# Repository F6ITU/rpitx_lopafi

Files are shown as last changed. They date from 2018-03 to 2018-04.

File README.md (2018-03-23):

# rpitx_lopafi

Low pass filter for the Raspberry-Pi based TX RF transceiver

YAOHKP ! Yet another open hardware kicad project

LoPaFi is a "keep it simple stupid" version of a low pass filter with a Raspberry-Pi (or Up Board) form factor.

It is intended to fit on a RP Board running RpiTX by F5OEO

https://github.com/F5OEO/rpitx

This filter is made of 5 different Cauer filters with rejection notches on F2 and F3, using T50 toroids and 1206 smd caps

Switching is made with NEC EC2-5NU miniature relays (Kemet, NEC, Axicom), directly powered by the SoC board

Each relay is directly driven by a  bufferized and software driven GPIO

For more information, pse refer to the Wiki hosted on this very same wiki page
 
 This hardware development is "under construction" as long as a first version hasn't been "branched" 
 
 Please, do not fork before the first stable release unless you intend to contribute to the main development
 
 This project is protected by the CERN Open Hardware Licence https://www.ohwr.org/projects/cernohl/wiki

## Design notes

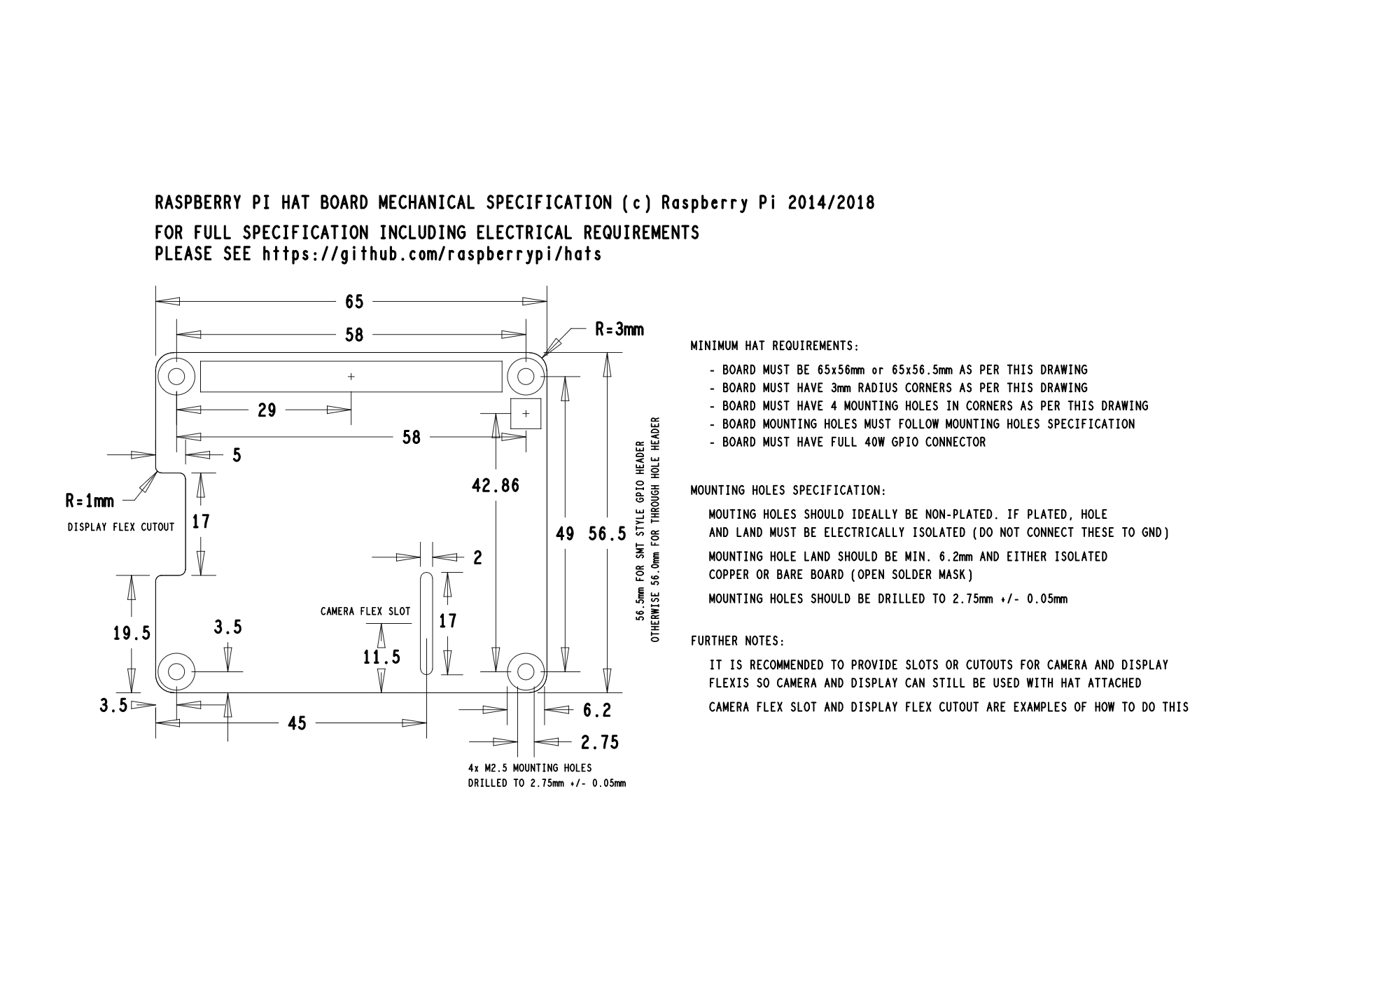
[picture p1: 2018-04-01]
datasheets/raspi specs.png

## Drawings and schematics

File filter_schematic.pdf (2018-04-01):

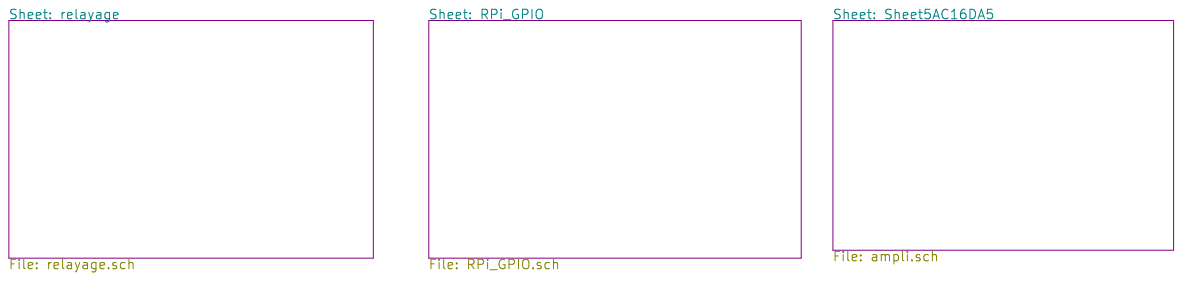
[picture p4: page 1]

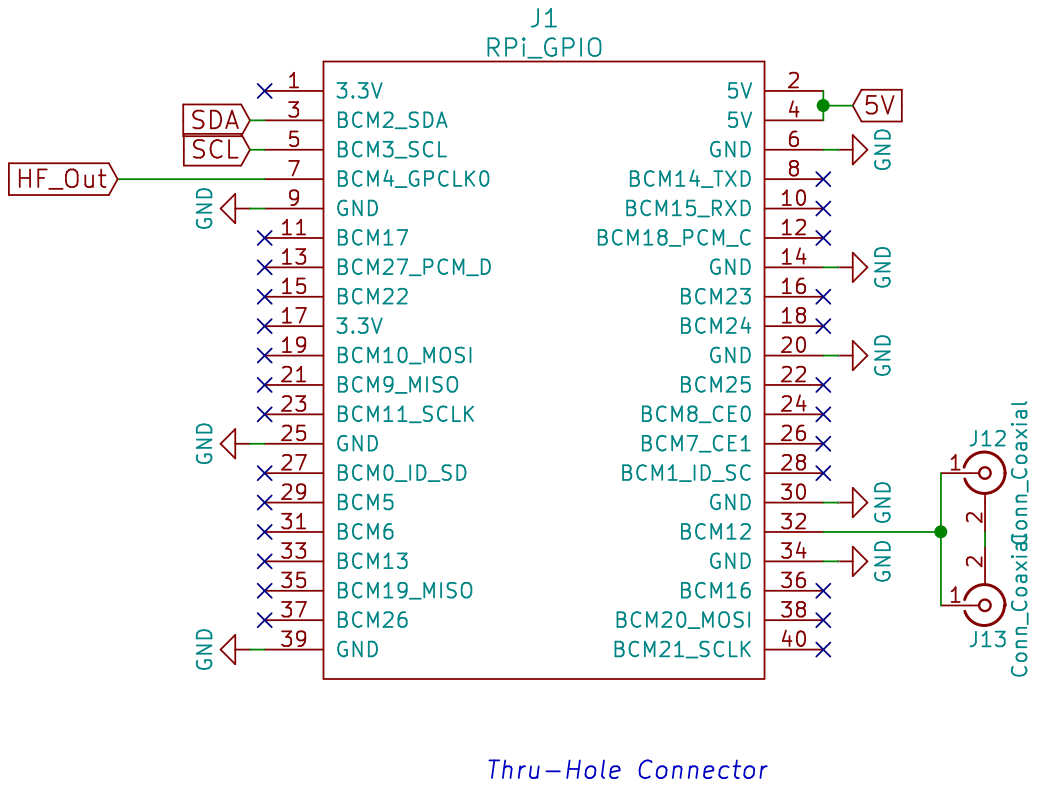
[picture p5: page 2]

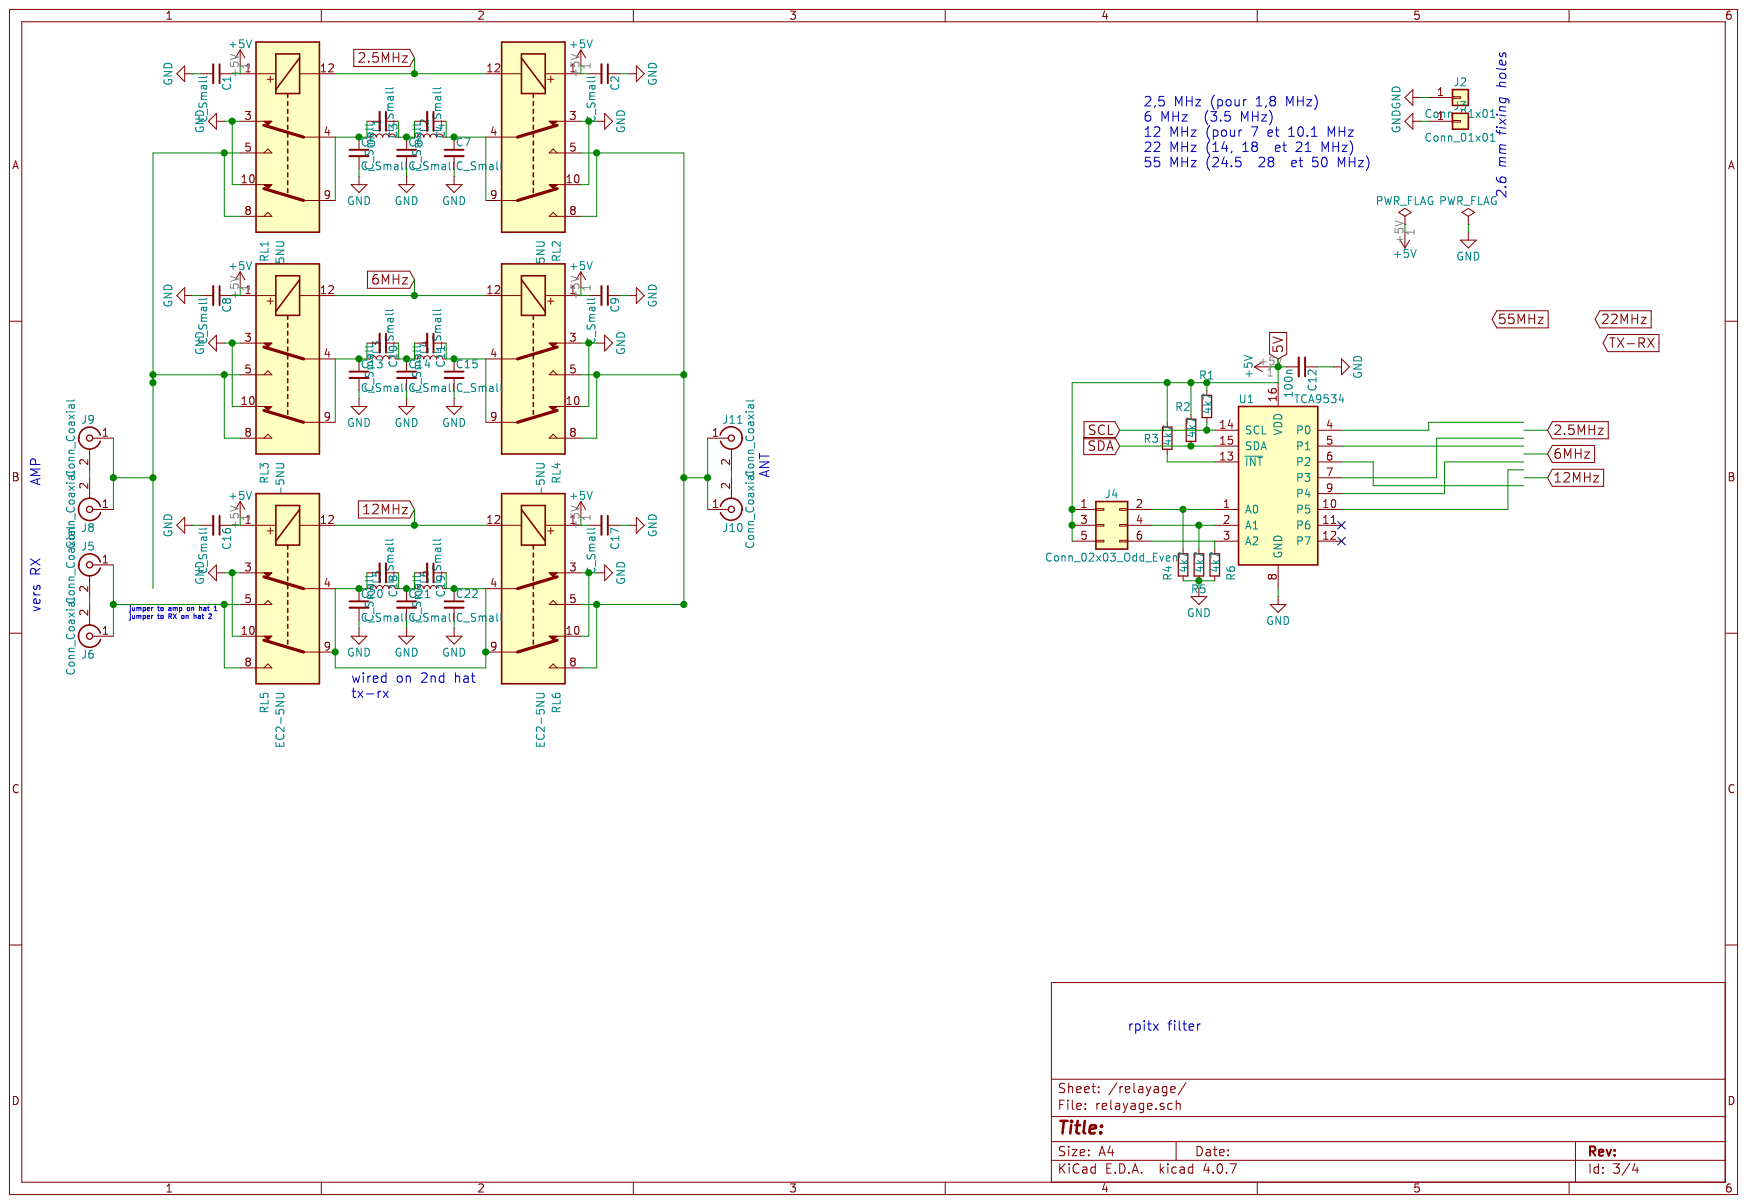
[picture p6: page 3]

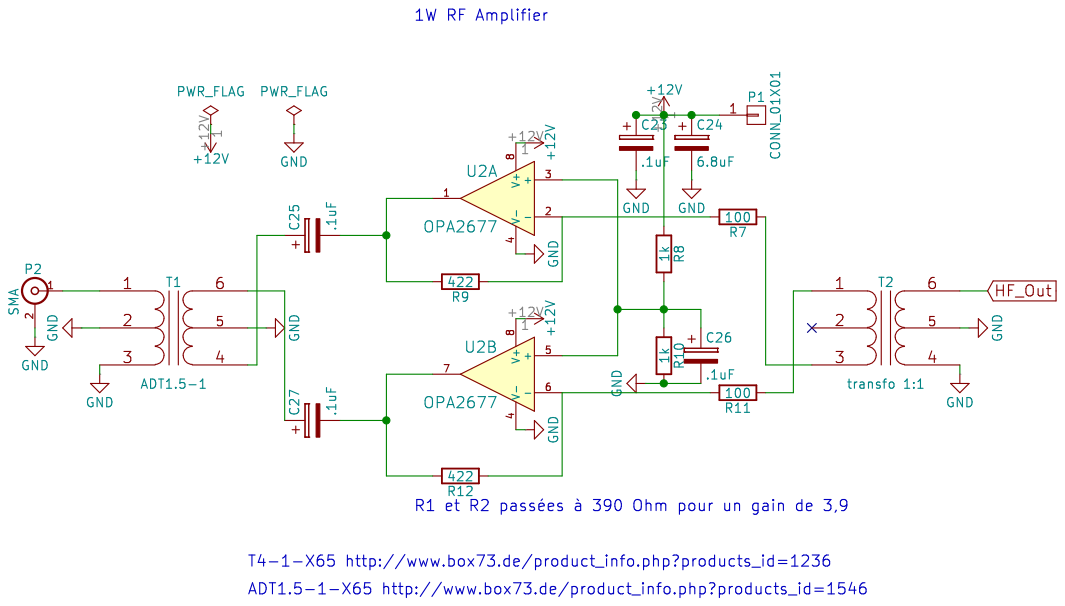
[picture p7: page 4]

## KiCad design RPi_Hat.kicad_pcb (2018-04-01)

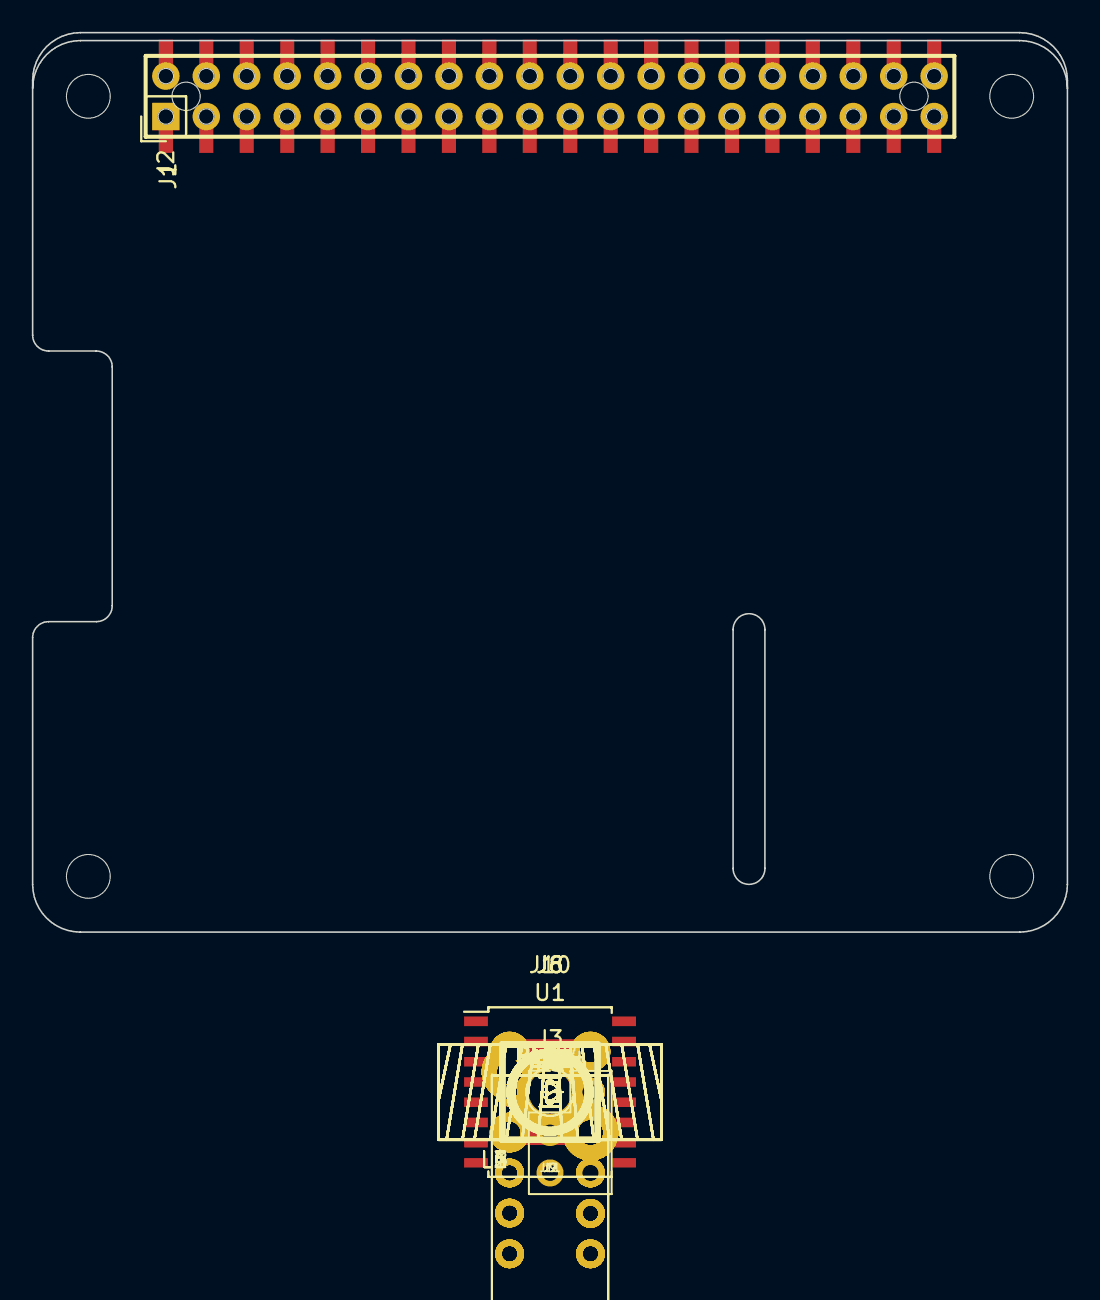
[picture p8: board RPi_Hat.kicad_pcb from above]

Board: 2 copper layers, 65.0 x 56.5 mm, 51 parts (0 on the bottom side), 26 nets, no tracks yet.

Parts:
C1, C2, C3, C4, C5, C6, C7, C8, C9, C10, C11, C13, C14, C15, C16, C17, C18, C19, C20, C21, C22: C_Small; C_1206_3216Metric_Pad1.24x1.80mm_HandSolder
C12: 100n; C_1206_3216Metric_Pad1.24x1.80mm_HandSolder
J1: RPi_GPIO; Samtec_HLE-120-02-XXX-DV-BE-XX-XX
J2: Conn_01x01; Pin_Header_Straight_2x20
J3: Conn_01x01; MountingHole_2.7mm_M2.5_DIN965_Pad
J4: Conn_02x03_Odd_Even; PinHeader_2x03_P2.54mm_Vertical
J6, J8, J10: Conn_Coaxial; SMA_EDGE_NRW
J7, J9, J11: Conn_Coaxial; SMA_PINS
L1, L2, L3, L4, L5, L6: L_Small; T50_V_THT
R1, R2, R3, R4, R5, R6: 4k7; R_0805_2012Metric_Pad1.15x1.50mm_HandSolder
RL1, RL2, RL3, RL4, RL5, RL6: EC2-5NU; Relay_DPDT_NEC_EC2
U1: TCA9534; SOIC-16W_7.5x10.3mm_P1.27mm

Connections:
2.5MHz: RL1.12, RL2.12, U1.4
5V: C1.1, C2.2, C8.1, C9.2, C12.2, C16.1, C17.2, J4.1, J4.3, J4.5, R1.1, R2.1, R3.1, RL1.1, RL2.1, RL3.1, RL4.1, RL5.1, RL6.1, U1.16
6MHz: RL3.12, RL4.12, U1.5
12MHz: RL5.12, RL6.12, U1.6
GND: C1.2, C2.1, C5.2, C6.2, C7.2, C8.2, C9.1, C12.1, C13.2, C14.2, C15.2, C16.2, C17.1, C20.2, C21.2, C22.2, J2.1, J3.1, R4.2, R5.2, R6.2, RL1.3, RL1.10, RL2.3, RL2.10, RL3.3, RL3.10, RL4.3, RL4.10, RL5.3, RL5.10, RL6.3, RL6.10, U1.8
unnamed: C3.1, C4.2, C6.1, L1.2, L2.1
unnamed: C3.2, C5.1, L1.1, RL1.4, RL1.9
unnamed: C4.1, C7.1, L2.2, RL2.4, RL2.9
unnamed: C10.1, C11.2, C14.1, L3.2, L4.1
unnamed: C10.2, C13.1, L3.1, RL3.4, RL3.9
unnamed: C11.1, C15.1, L4.2, RL4.4, RL4.9
unnamed: C18.1, C19.2, C21.1, L5.2, L6.1
unnamed: C18.2, C20.1, L5.1, RL5.4, RL5.9
unnamed: C19.1, C22.1, L6.2, RL6.4, RL6.9
unnamed: J4.2, R4.1, U1.1
unnamed: J4.4, R5.1, U1.2
unnamed: J4.6, R6.1, U1.3
unnamed: J6.1, J7.1
unnamed: J6.2, J7.2
unnamed: J8.1, J9.1, RL1.5, RL1.8, RL3.5, RL3.8, RL5.5, RL5.8
unnamed: J8.2, J9.2
unnamed: J10.1, J11.1, RL2.5, RL2.8, RL4.5, RL4.8, RL6.5, RL6.8
unnamed: J10.2, J11.2
unnamed: R3.2, U1.13
SCL: R1.2, U1.14
SDA: R2.2, U1.15

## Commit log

2018-03-24 first commit, first half-schematic
    [Lopafi2.sch, lopafi.kicad_pcb, lopafi.sch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]
2018-03-25 first schematic
    [Lopafi2.sch, lopafi.sch, lopafi1.sch]
2018-04-01 whole schematic, first draft
    [lopafi.sch, lopafi1.sch]
